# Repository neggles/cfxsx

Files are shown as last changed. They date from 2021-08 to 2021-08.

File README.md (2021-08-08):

# cfxsx

Xbox Series X/S storage expansion card to M.2 NGFF NVMe SSD adapter. Well, maybe.

The connector the X/S use is CFexpress-adjacent - I have _no idea_ if this will even begin to work, but, YOLO?

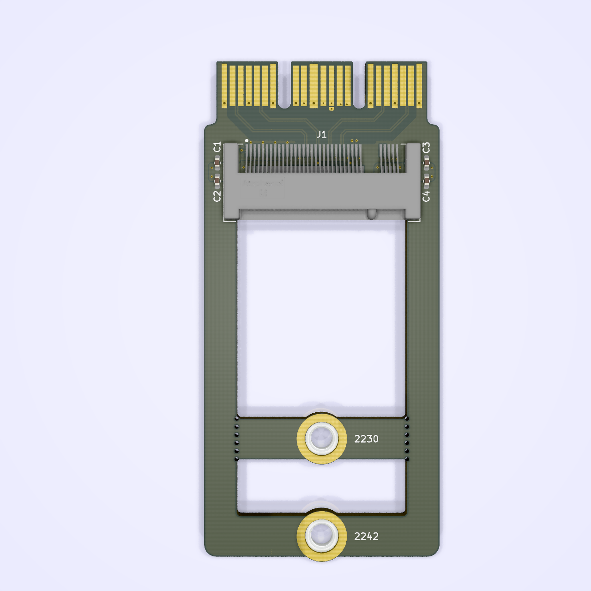
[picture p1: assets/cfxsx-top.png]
KiCad raytraced board render


# But, for real, don't make this. It probably doesn't work at all.

## Repository Structure
- `cfxsx` contains the main schematics and board drawing
- `cfxsx/PCIexpress.pretty` contains the board-specific footprints
- `cfxsx/PCIexpress.3dshapes` contains the 3D models for parts on the board (and a bunch of extras from my various experiments)

## Building
Simply call `make` in the top-top level directory. The `build` directory will then contain:

- the main board
- zipped gerbers for the boards you can directly use for manufacturing
- zipped gerbers and SMT assembly BOM/position files for JLCPCB's SMT assembly service for the single-board version.

Makefile uses [Jan Mrázek](https://github.com/yaqwsx)'s [KiKit](https://github.com/yaqwsx/KiKit), which I cannot recommend enough, and therefore has to be available on your system.

Jan's [jlcparts](https://yaqwsx.github.io/jlcparts/) app was also extremely useful in narrowing down part choices based on what JLCPCB have available.

-----
### **IMPORTANT NOTE:** If you give JLCPCB these files as-is, *please* verify the orientation of every part before submitting.

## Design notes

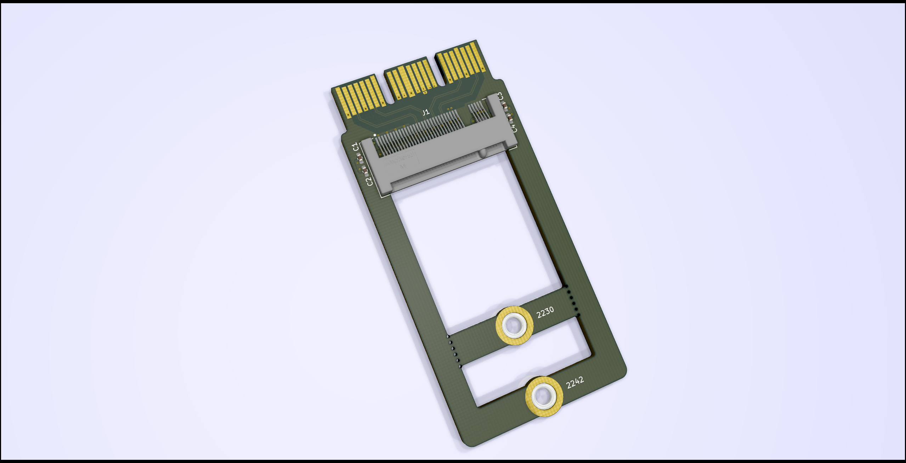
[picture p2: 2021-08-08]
assets/cfxsx.png

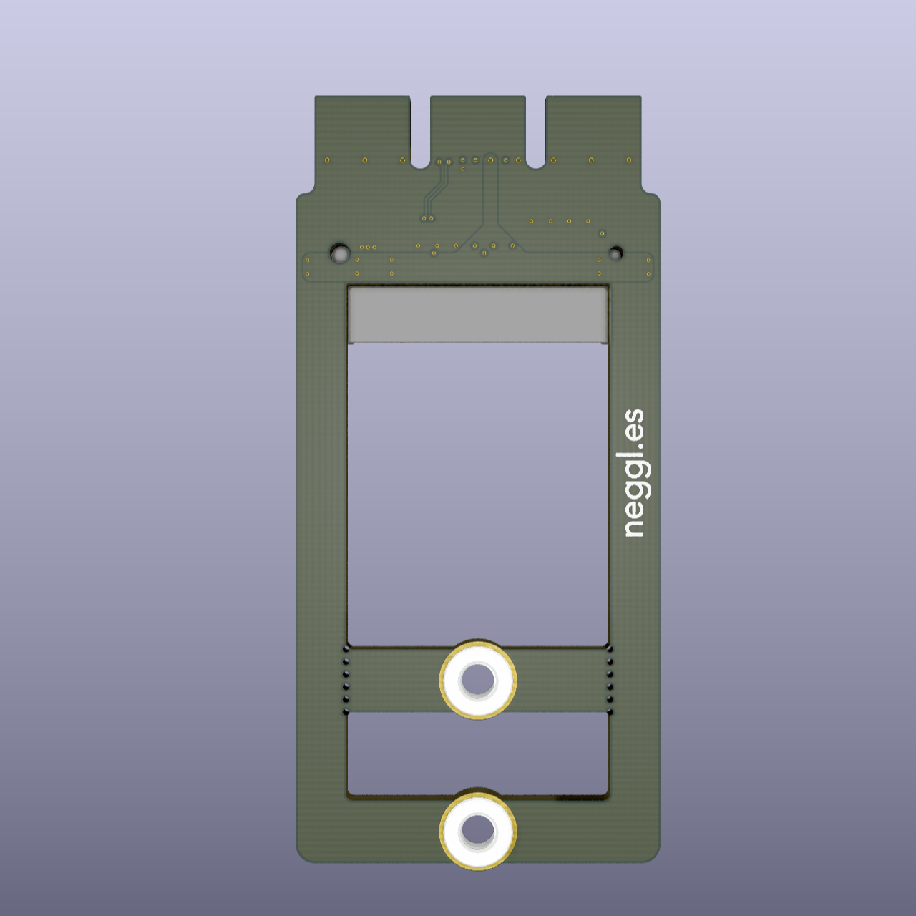
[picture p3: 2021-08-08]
assets/cfxsx-bottom.png

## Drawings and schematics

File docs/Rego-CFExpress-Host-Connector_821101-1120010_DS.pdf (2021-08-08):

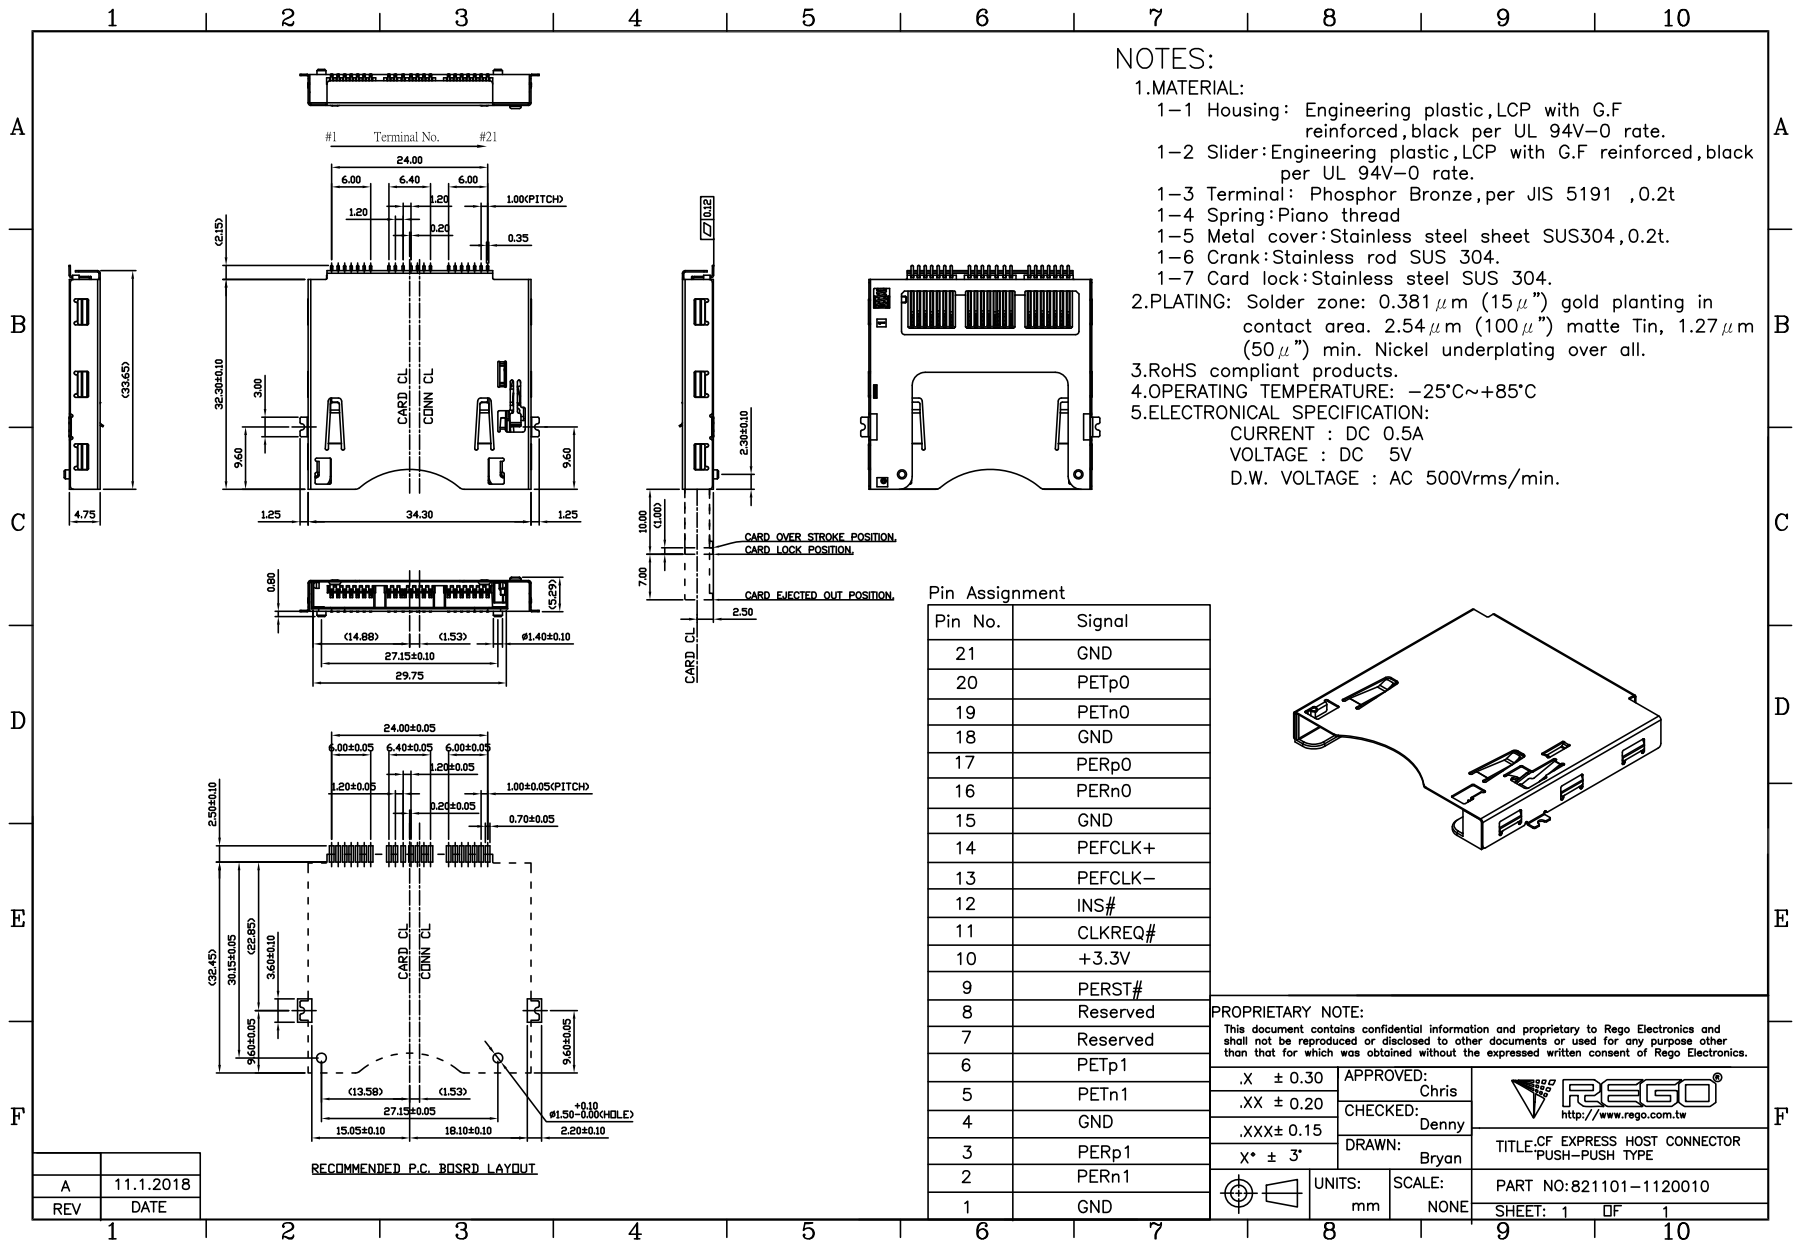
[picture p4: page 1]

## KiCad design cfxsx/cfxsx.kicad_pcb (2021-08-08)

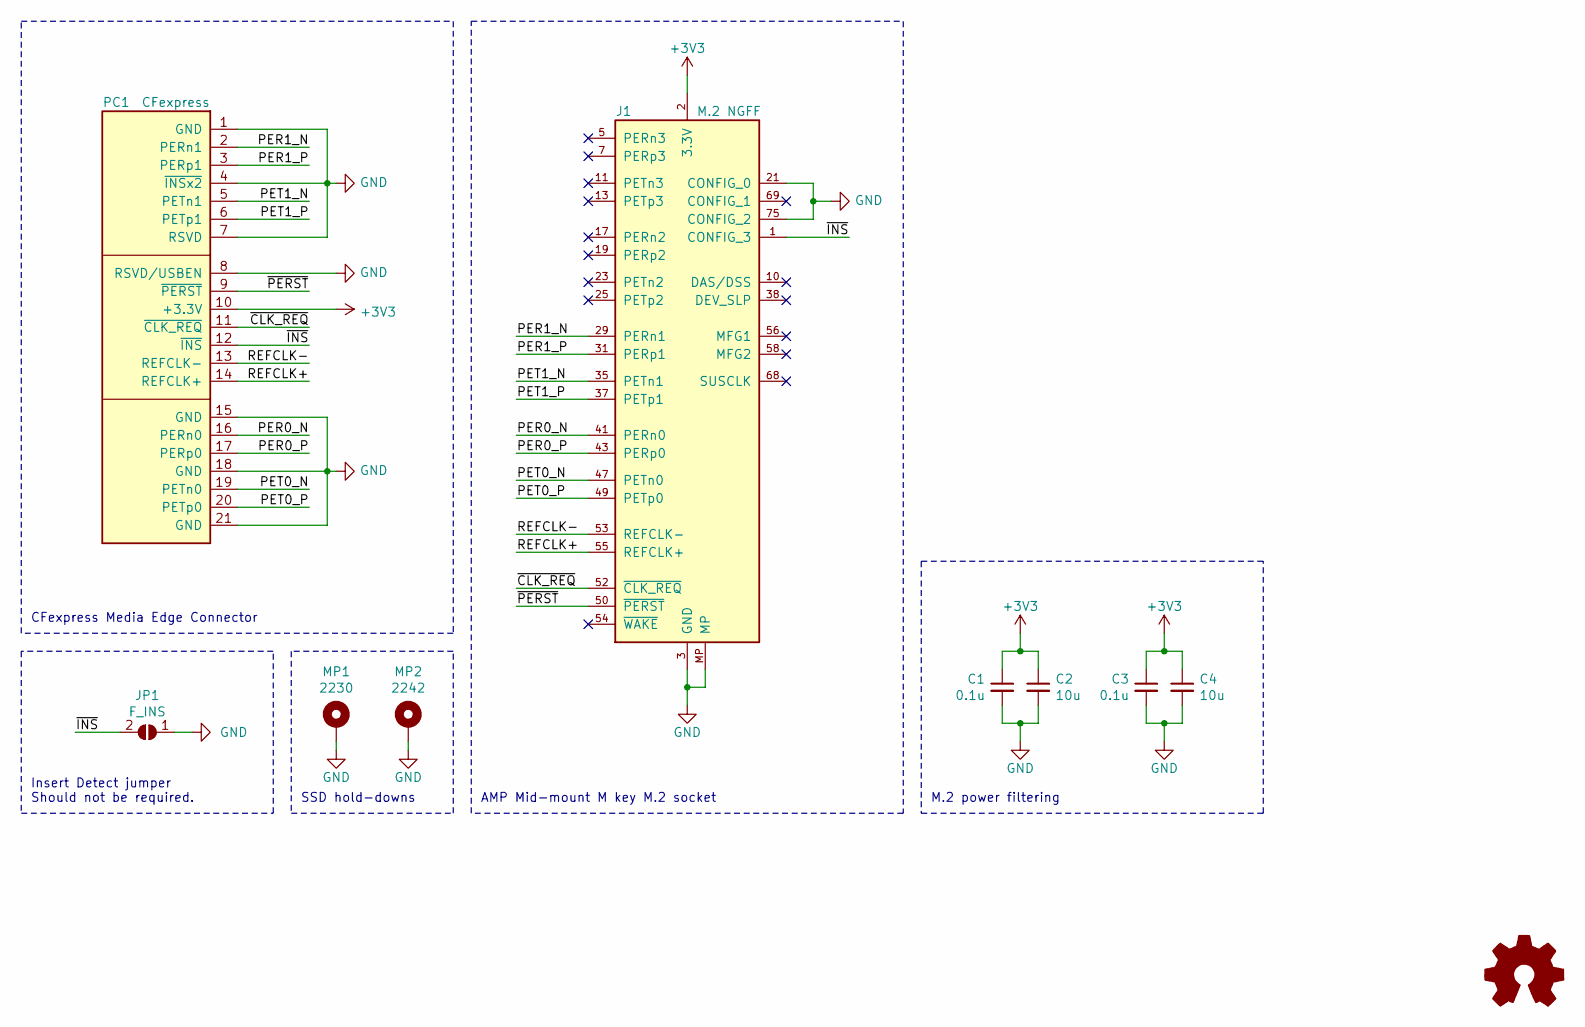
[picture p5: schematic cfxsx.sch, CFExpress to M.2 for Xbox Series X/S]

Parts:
C1, C3: 0.1u; C_0402_1005Metric_Pad0.74x0.62mm_HandSolder
C2, C4: 10u; C_0402_1005Metric_Pad0.74x0.62mm_HandSolder
J1: M.2 NGFF; AMP_MDT180xxx001_NGFF-KeyM; MPN MDT180M03001
JP1: F_INS; SolderJumper-2_P0.6mm_Open_RoundedPad1.0x1.5mm
MP1: 2230; MountingHole_NGFF_4.2mm_Pad_TopBottom
MP2: 2242; MountingHole_NGFF_4.2mm_Pad_TopBottom
PC1: CFexpress; CFExpress_Media
SYM1: logo; neggle-logo-0.12

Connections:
+3V3: C1.1, C2.1, C3.1, C4.1, J1.2 (3.3V), J1.4 (3.3V), J1.12 (3.3V), J1.14 (3.3V), J1.16 (3.3V), J1.18 (3.3V), J1.70 (3.3V), J1.72 (3.3V), J1.74 (3.3V), PC1.10 (+3.3V)
/PER0_N: J1.41 (PERn0), PC1.16 (PERn0)
/PER0_P: J1.43 (PERp0), PC1.17 (PERp0)
/PER1_N: J1.29 (PERn1), PC1.2 (PERn1)
/PER1_P: J1.31 (PERp1), PC1.3 (PERp1)
/PET0_N: J1.47 (PETn0), PC1.19 (PETn0)
/PET0_P: J1.49 (PETp0), PC1.20 (PETp0)
/PET1_N: J1.35 (PETn1), PC1.5 (PETn1)
/PET1_P: J1.37 (PETp1), PC1.6 (PETp1)
/REFCLK+: J1.55 (REFCLK+), PC1.14 (REFCLK+)
/REFCLK-: J1.53 (REFCLK-), PC1.13 (REFCLK-)
/~CLK_REQ: J1.52 (~CLK_REQ), PC1.11 (~CLK_REQ)
/~INS: J1.1 (CONFIG_3), JP1.2 (B), PC1.12 (~INS)
/~PERST: J1.50 (~PERST), PC1.9 (~PERST)
GND: C1.2, C2.2, C3.2, C4.2, J1.3 (GND), J1.9 (GND), J1.15 (GND), J1.21 (CONFIG_0), J1.27 (GND), J1.33 (GND), J1.39 (GND), J1.45 (GND), J1.51 (GND), J1.57 (GND), J1.71 (GND), J1.73 (GND), J1.75 (CONFIG_2), J1.MP, JP1.1 (A), MP1.1, MP2.1, PC1.1 (GND), PC1.4 (~INSx2), PC1.7 (RSVD), PC1.8 (RSVD/USBEN), PC1.15 (GND), PC1.18 (GND), PC1.21 (GND)

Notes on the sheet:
CFexpress Media Edge Connector
Insert Detect jumper Should not be required.
SSD hold-downs
AMP Mid-mount M key M.2 socket
M.2 power filtering

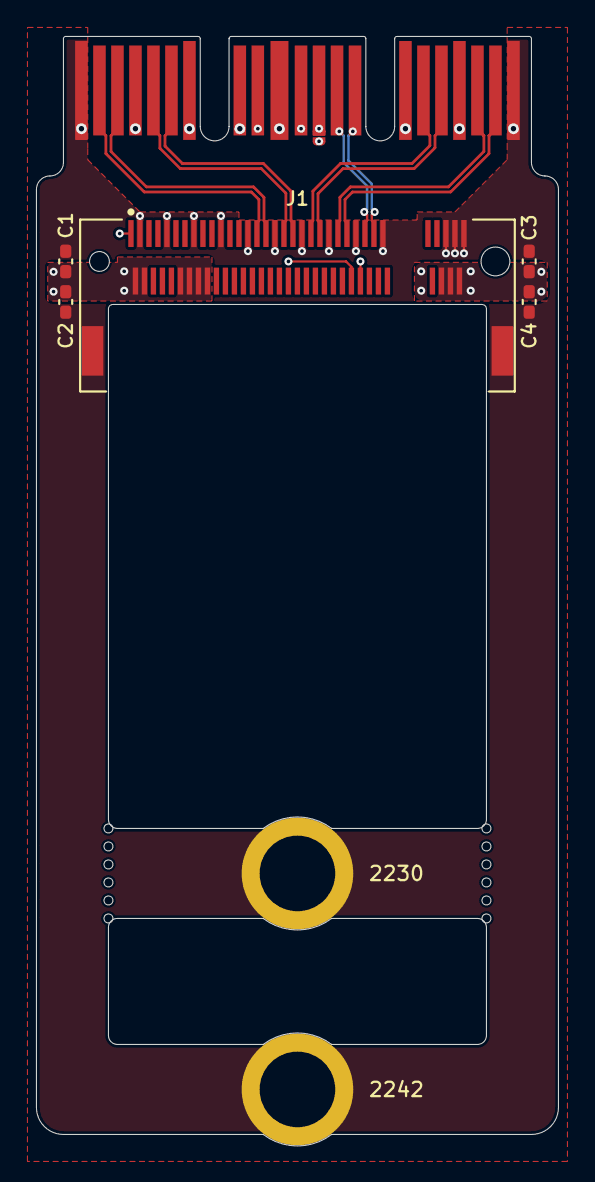
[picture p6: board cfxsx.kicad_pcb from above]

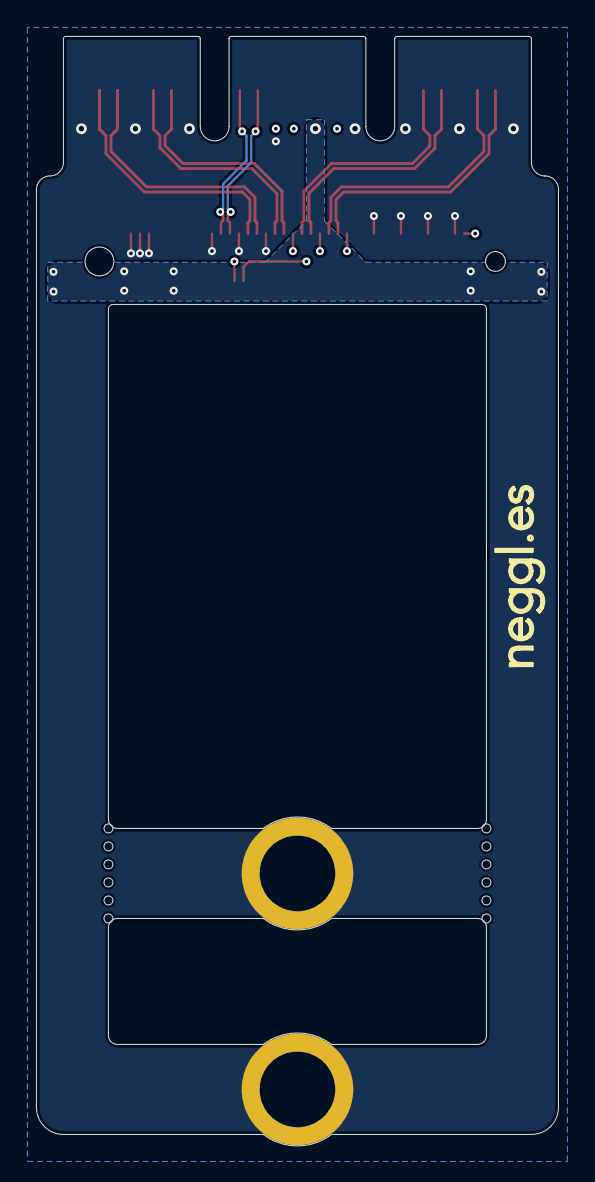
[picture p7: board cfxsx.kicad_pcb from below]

Board: 4 copper layers, 29.0 x 61.6 mm, 10 parts (3 on the bottom side), 15 nets.

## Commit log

2021-08-08 add 2280
    [cfxsx-2280.kicad_pcb]
2021-08-08 add 2280 board to the makefile
